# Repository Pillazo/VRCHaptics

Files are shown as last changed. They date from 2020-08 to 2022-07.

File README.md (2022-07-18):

# VRCHaptics
 VRC Haptics
A haptics set of software and hardware to give haptic feedback to VRChat on more than just your controllers. Old version used a melon-loader side-loaded dll file to pull bone positions out and set haptics. New version now uses the approved OSC system, by setting up the avatar in unity with 'VRC Contact Recievers'. A VB.NET program then grabs the OSC commands and then determines to turn on or off vibrating nodes you've mounted to yourself wherever!

A working example video here: https://youtu.be/_tgKSILLgIA

Node Assembly Video: https://youtu.be/x2D46sjlmms

Controller Assembly Video: https://youtu.be/UboYsb8L9xo

Controller Overview and use: https://youtu.be/rSFWYQzmyZ4

VB.Net program and use: https://youtu.be/C1V2dHkt9lk

Adding the Udon to your world: https://youtu.be/wW_y7pmaBFk

Find my project's discord at https://discord.gg/QjyNznq

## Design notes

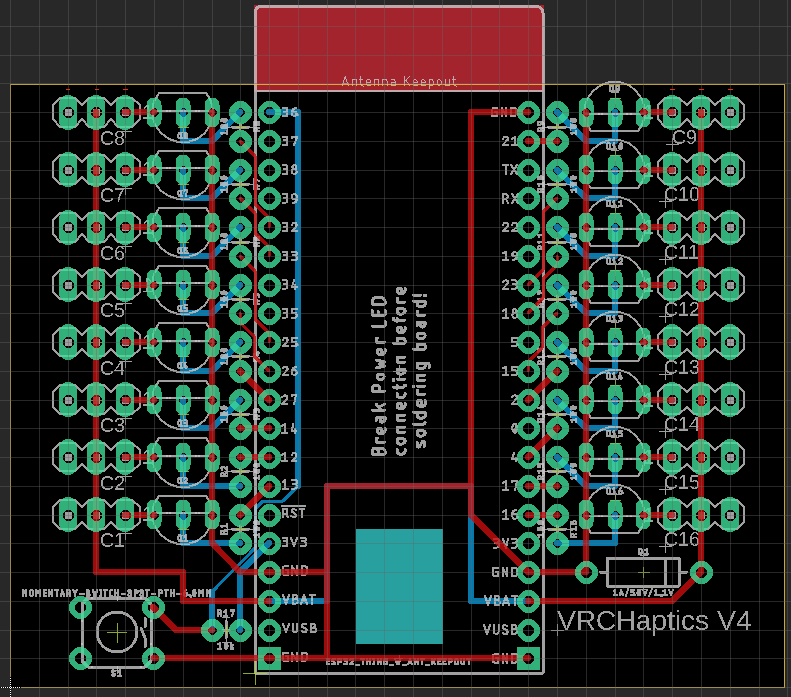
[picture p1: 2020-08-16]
Haptics Hardware/BoardLayout.PNG

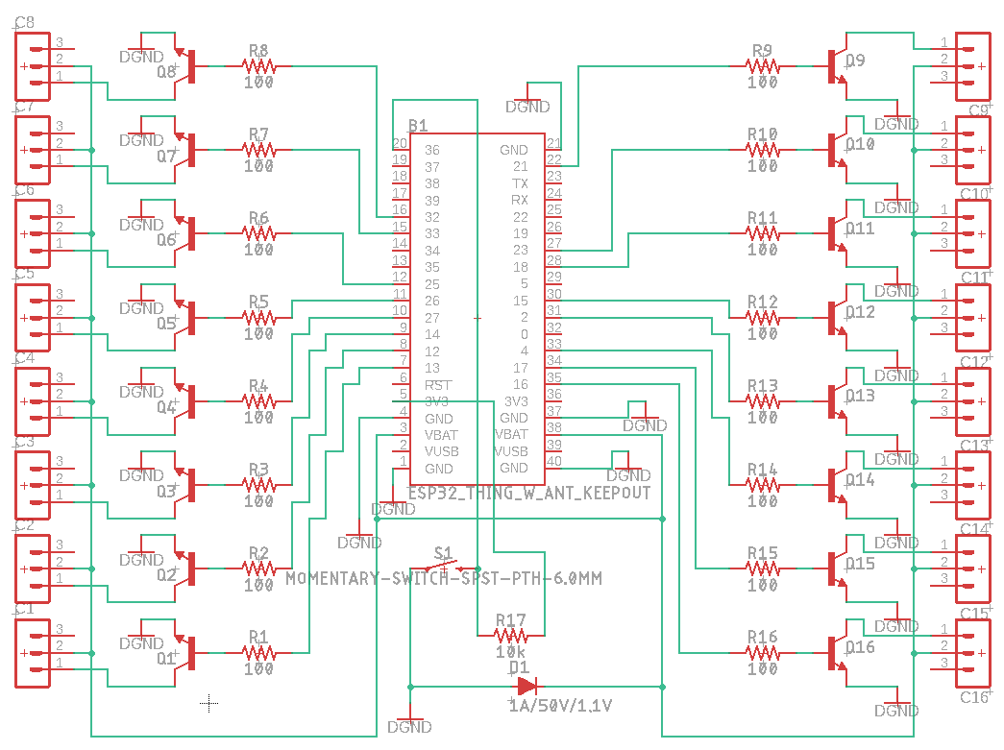
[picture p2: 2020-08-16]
Haptics Hardware/Schematic.PNG

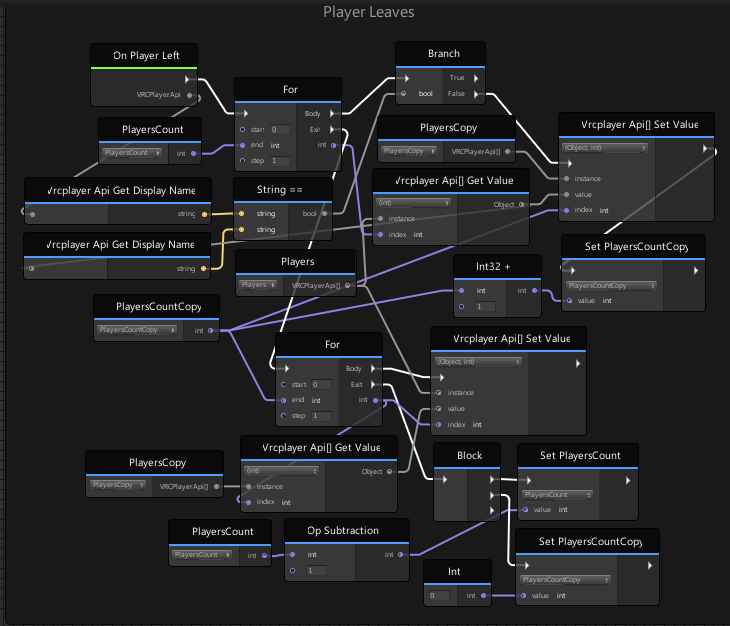
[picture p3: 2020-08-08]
VRChat Udon/Player Leaves.PNG

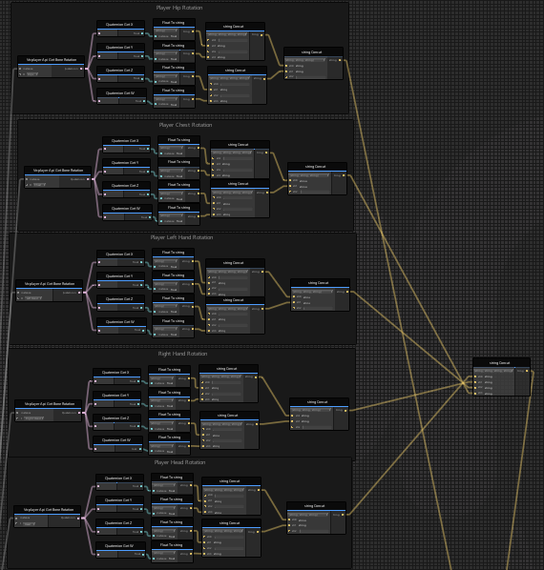
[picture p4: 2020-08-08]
VRChat Udon/Player Rotations.PNG

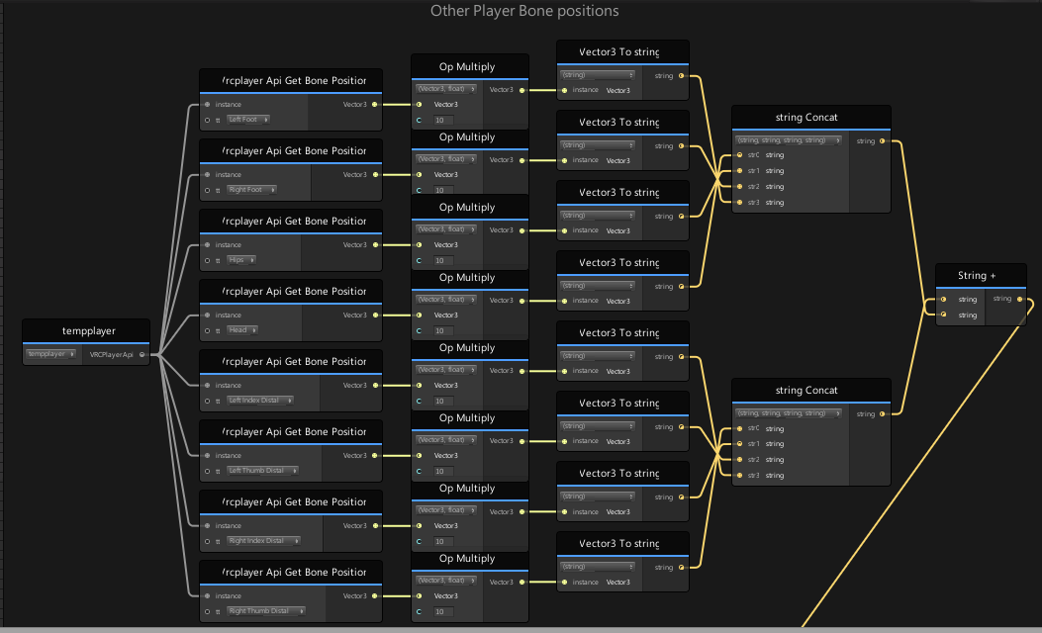
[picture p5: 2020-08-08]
VRChat Udon/Other player bones.PNG

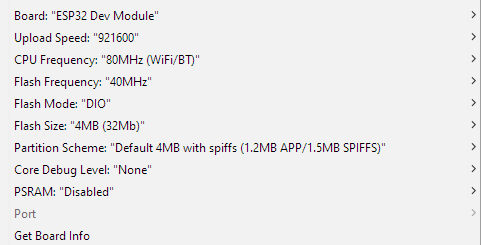
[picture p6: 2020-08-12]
VRCHaptics Controller Software/Settings.PNG

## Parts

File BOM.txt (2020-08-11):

25 Piece Cables
https://www.amazon.com/25Pcs-Remote-Control-Extension-Female/dp/B07L28M5W4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

Long Cables
https://www.amazon.com/gp/product/B01HLUZQ5A/ref=ppx_yo_dt_b_asin_title_o01_s00?ie=UTF8&psc=1

Jumper Wire (to be divided to 2)
https://www.sparkfun.com/products/13164
https://www.amazon.com/gp/product/B016RJ8S42/ref=ppx_yo_dt_b_asin_title_o00_s00?ie=UTF8&psc=1

Battery
https://www.sparkfun.com/products/13855 2Ah
https://www.adafruit.com/product/2011 2Ah

Controller
https://www.sparkfun.com/products/13907
https://www.amazon.com/gp/product/B01MG9BNEN/ref=ppx_yo_dt_b_asin_title_o04_s01?ie=UTF8&psc=1

Vibe Motor
https://www.digikey.com/product-detail/en/1201/1528-1177-ND/5353637/?itemSeq=325918176
https://www.amazon.com/gp/product/B07Q1ZV4MJ/ref=ppx_yo_dt_b_asin_title_o03_s01?ie=UTF8&psc=1

Headers
https://www.amazon.com/gp/product/B06ZZN8L9S/ref=ppx_yo_dt_b_asin_title_o04_s01?ie=UTF8&psc=1
https://www.sparkfun.com/products/116
https://www.adafruit.com/product/392

Nylon Strap 1 inch
https://www.amazon.com/gp/product/B01KTVB0LC/ref=ppx_yo_dt_b_asin_title_o02_s00?ie=UTF8&psc=1

Velcro strap
https://www.homedepot.com/p/VELCRO-Brand-12-ft-x-3-4-in-One-Wrap-Strap-90340/202261925
https://www.amazon.com/VELCRO-Brand-ONE-WRAP-Tape-Yard/dp/B00RPOY384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

Bolt M3x20mm
https://www.amazon.com/gp/product/B07CJLVC17/ref=ppx_yo_dt_b_asin_title_o00_s00?ie=UTF8&psc=1

Bolt M3x10mm
https://www.amazon.com/gp/product/B07CK3RSN3/ref=ppx_yo_dt_b_asin_title_o00_s00?ie=UTF8&psc=1

Push button
https://www.sparkfun.com/products/97
https://www.adafruit.com/product/367
https://www.amazon.com/QTEATAK-Momentary-Tactile-Button-Switch/dp/B07VSNN9S2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

Diode
https://www.sparkfun.com/products/8589
https://www.adafruit.com/product/755
https://www.amazon.com/MCIGICM-Rectifier-Electronic-Silicon-Doorbell/dp/B071YWNBVM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

transistor
https://www.sparkfun.com/products/13689
https://www.adafruit.com/product/756
https://www.amazon.com/McIgIcM-2N2222-Transistor-2N2222A-Through/dp/B06XPWS52G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

resistor 100 ohm
https://www.adafruit.com/product/4293
https://www.sparkfun.com/products/14493
https://www.amazon.com/Projects-100EP514100R-100-Resistors-Pack/dp/B00AVSDYFO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

resistor 10K ohm
https://www.adafruit.com/product/2784
https://www.sparkfun.com/products/14491
https://www.amazon.com/Projects-100EP51410K0-10k-Resistors-Pack/dp/B0185FGYQA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

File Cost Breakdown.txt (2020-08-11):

Controller:
3D Prints (JT3DP Prices)
	-Main Body Top - $11
	-Main Body Board Holder - $8.50
	-Main Body Battery Adafruit - $12 / Main body Battery Sparkfun - $10
	-Main Body button - $0.50
	-Main Body Clip - $8.50 / Main Body Strap Mount - $7
Components
	-Sparkfun ESP32 Thing - $19.28
	-Battery - $13 Sparkfun, $12.50 Adafruit
	-Circuit Board - $25, $2.50ea
	-2x 20pos Headers - $11, $0.055ea
	-16x 3pos headers - $11, $0.00825ea
	-16x 100 ohm resistors - $0.75, 0.03ea
	-10K ohm resisitor - $0.75, 0.03ea
	-Push button - $2.50, 0.125ea
	-Diode - $0.15ea
	-16x Transistors - $1.95, $0.195ea
	-4x M3x20mm bolt - $9, $0.09ea
	-3x / 2x M3x10mm bolt - $7.65, $0.0765ea
	
Total:
3D print for adafruit battery and strap mount - $39
3D print for adafruit battery and clip mount - $40.5
3D print for sparkfun battery and strap mount - $37
3D print for sparkfun battery and clip mount - $38.5
Components for adafruit battery - $39
Components for sparkfun battery - $39.50

Total adafruit battery cost = $78
Total sparkfun battery cost = $76.5

Node
16x 3D Print - 1in - $4
16x 3D Print - 0.75in - $3.50
16x Vibration Motor - $15, $0.75ea
16x Half Servo Cable - $8, $0.40ea
Velcro 3/4in strap - $0.34/ft - 12ft = $4.08
2x / 2x M3x10mm bolt - $7.65, $0.0765ea

Cables
	-Assorted length extensions - $12, $0.60ea
	-1 meter length extensions - $21.47, $0.72ea
	
Velcro Straps

Total: 16x - 1in $84.96, 5.31ea
		   - .75in $76.8, 4.80ea

Total controller + 16 Nodes = $153
Total controller + 16 nodes + 16 1-meter cables  + 12ft velcro = $168.9
+ shipping for battery = 182.73

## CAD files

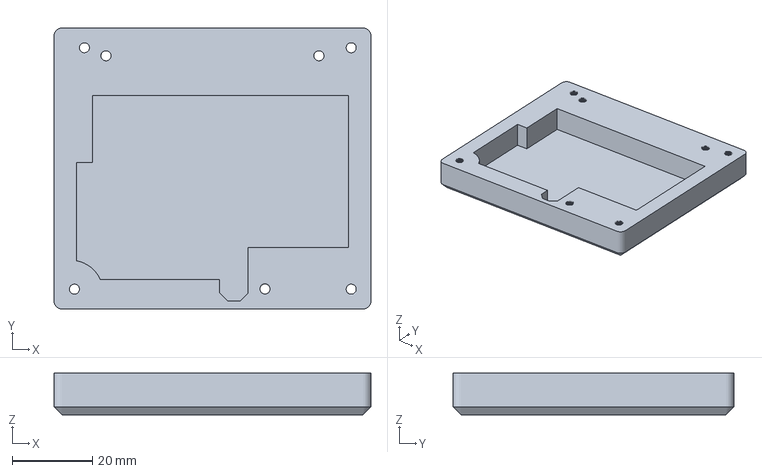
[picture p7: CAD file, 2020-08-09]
VRCHaptics 3D files/Main Body Adafruit Battery.3mf
79.2 x 70.2 x 10.4 mm

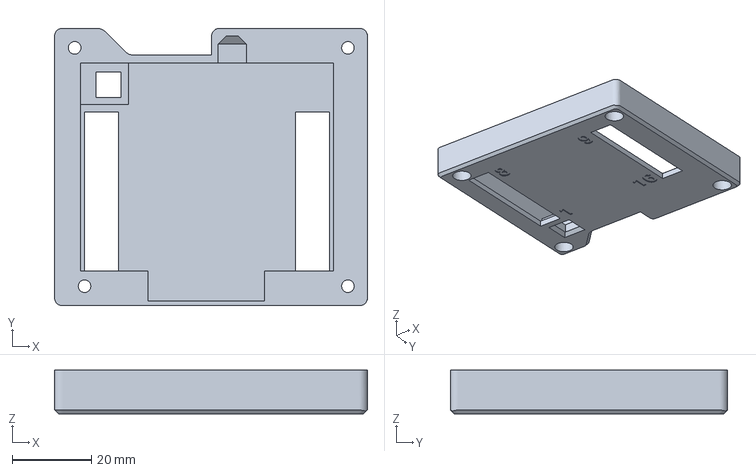
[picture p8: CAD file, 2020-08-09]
VRCHaptics 3D files/Main Body.3mf
79.2 x 70.2 x 11.1 mm

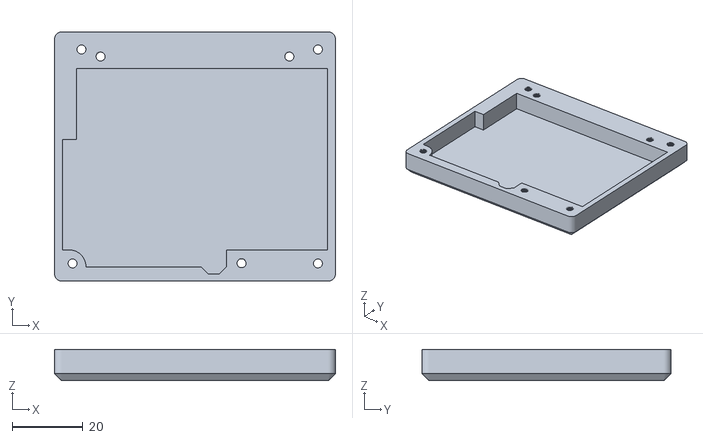
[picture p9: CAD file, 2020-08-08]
VRCHaptics 3D files/Main Body SparkFun Battery.stl
79.2 x 70.2 x 8.80

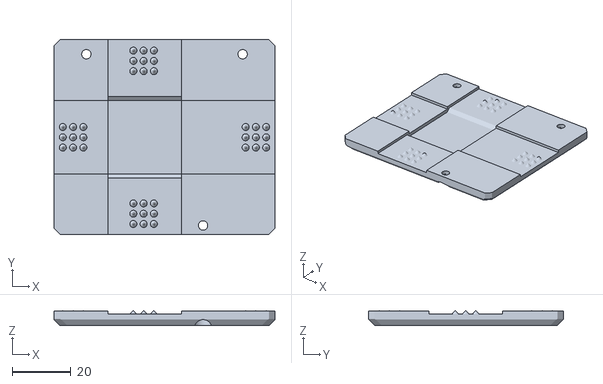
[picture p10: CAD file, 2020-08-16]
VRCHaptics 3D files/Strip Mount.stl
75.2 x 66.2 x 5.10

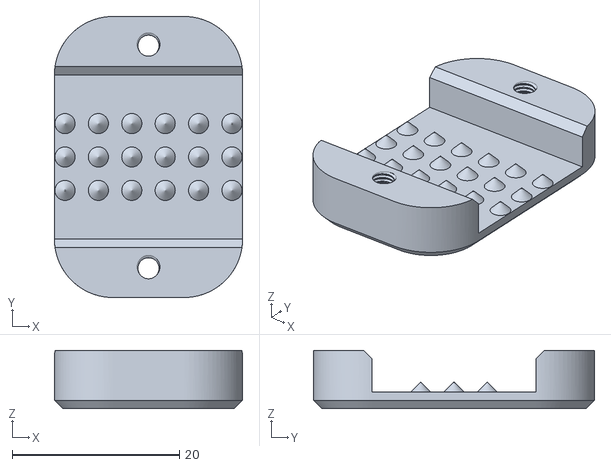
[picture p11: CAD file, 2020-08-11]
VRCHaptics 3D files/NodeBottom2Way-.75in.stl
22.5 x 33.7 x 7.00

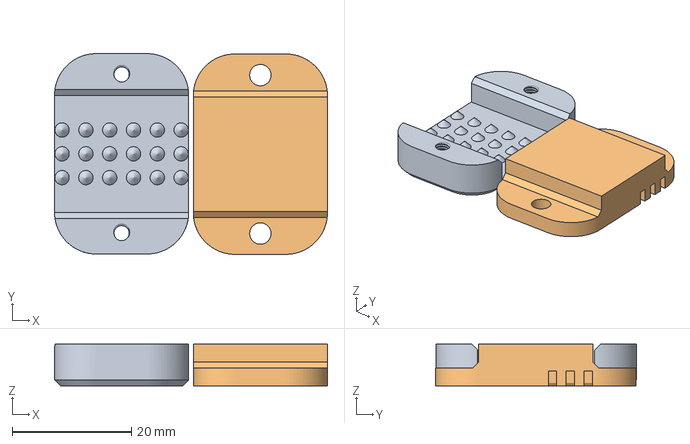
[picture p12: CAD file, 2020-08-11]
VRCHaptics 3D files/Node2Way-.75in.3mf
45.8 x 33.7 x 7.00 mm
NodeBottom2Way-.75in.stl
NodeTop2Way-.75in.stl

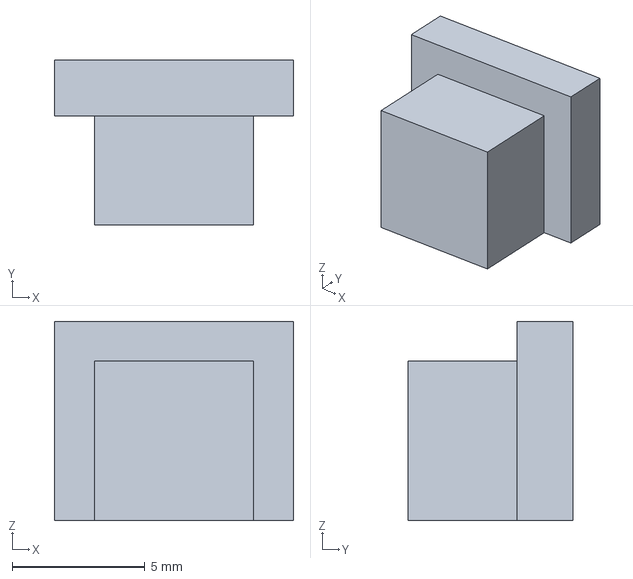
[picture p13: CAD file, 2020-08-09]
VRCHaptics 3D files/Button.3mf
9.00 x 6.20 x 7.50 mm

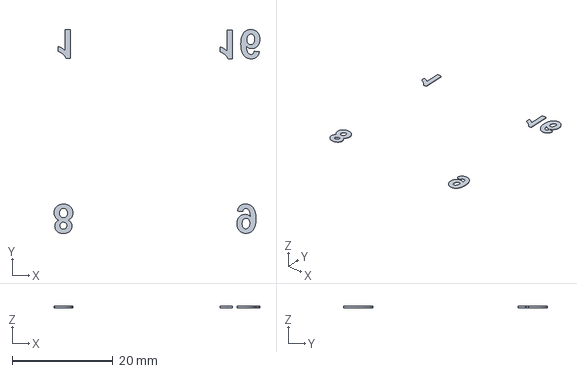
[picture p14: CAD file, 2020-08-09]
VRCHaptics 3D files/Text.3mf
40.9 x 40.5 x 0.3 mm

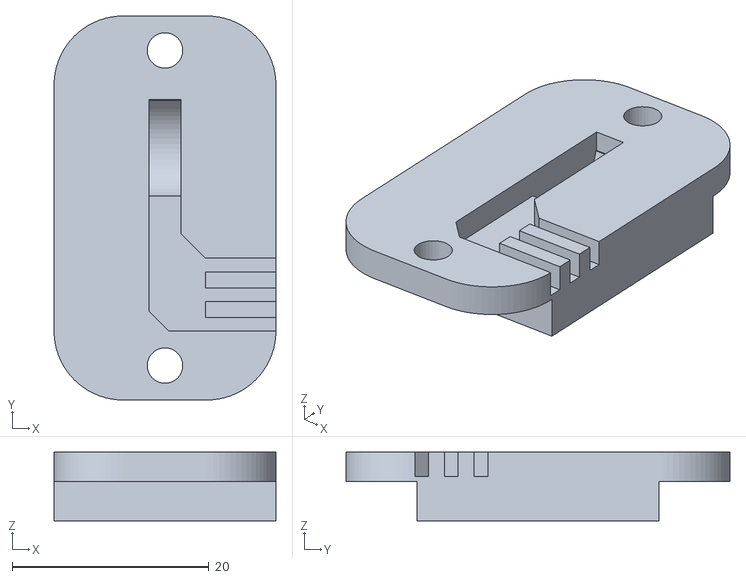
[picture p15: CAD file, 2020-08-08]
VRCHaptics 3D files/NodeTop2Way.stl
22.5 x 39.0 x 7.00

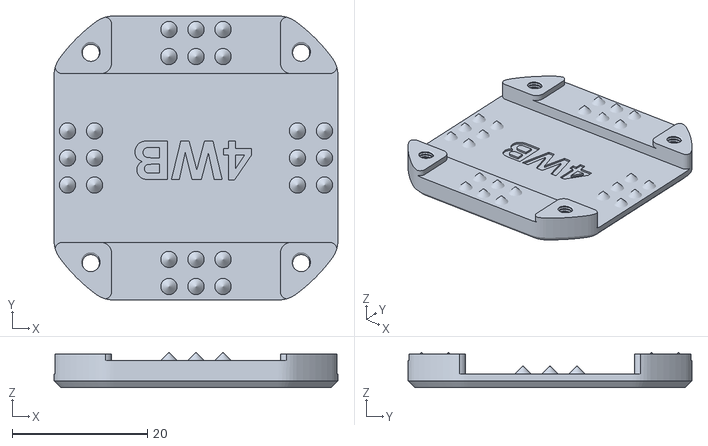
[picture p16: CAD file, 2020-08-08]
VRCHaptics 3D files/NodeBottom4Way.stl
42.0 x 42.0 x 5.21

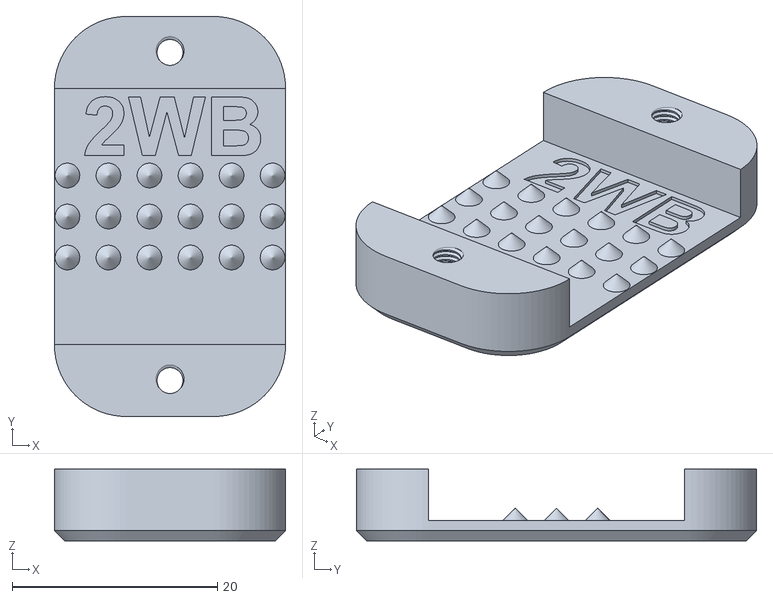
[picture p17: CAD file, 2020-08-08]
VRCHaptics 3D files/NodeBottom2Way.stl
22.5 x 39.0 x 7.00

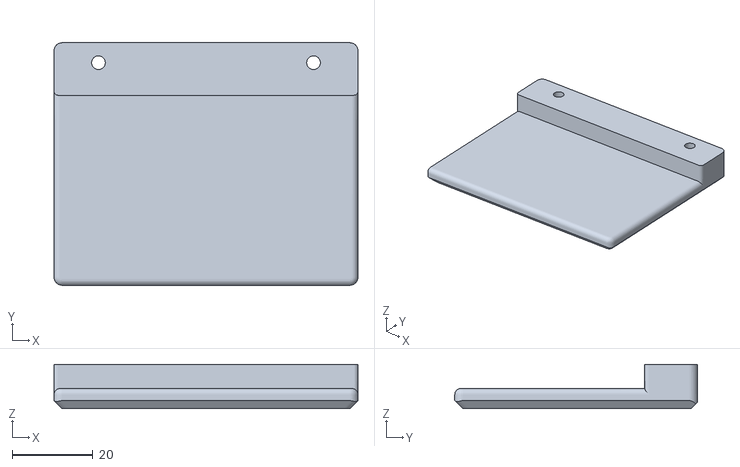
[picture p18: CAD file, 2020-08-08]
VRCHaptics 3D files/Clip.stl
75.2 x 60.0 x 11.0

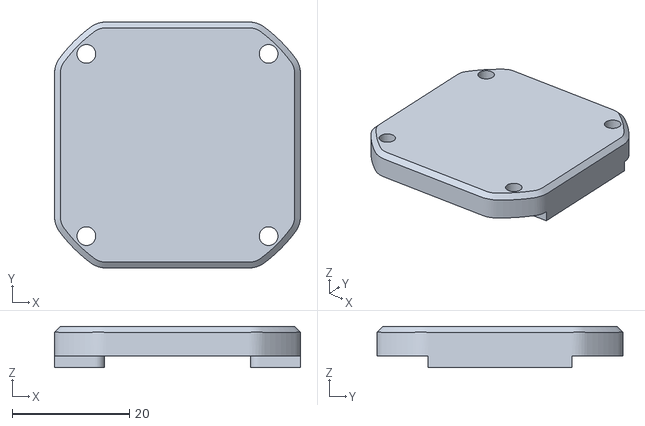
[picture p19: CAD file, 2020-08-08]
VRCHaptics 3D files/NodeTop4Way.stl
42.0 x 42.0 x 7.00

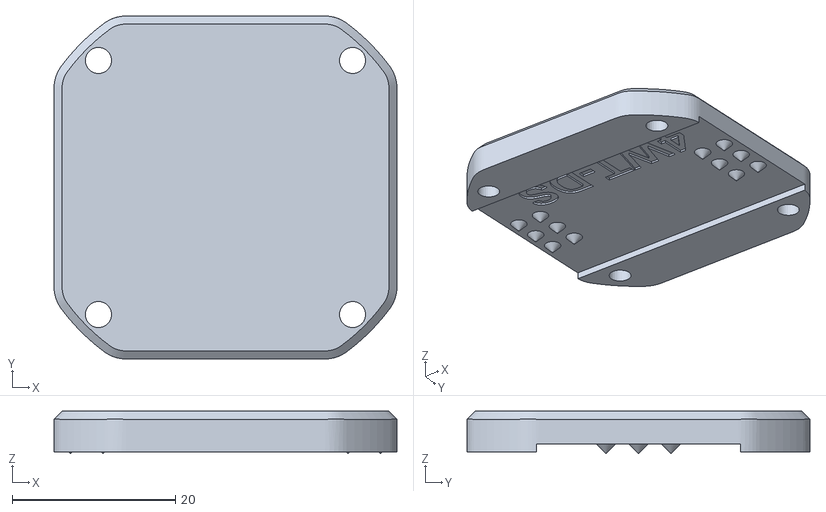
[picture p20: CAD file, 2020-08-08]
VRCHaptics 3D files/NodeTop4Way-DoubleStrap.stl
42.0 x 42.0 x 5.21

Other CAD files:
VRCHaptics 3D files/NodeTop2Way-.75in.stl
VRCHaptics 3D files/Ring.stl
VRCHaptics 3D files/Main Body (1).3mf
VRCHaptics 3D files/Button.stl
VRCHaptics 3D files/Main Body (1).stl
VRCHaptics 3D files/Main Body Adafruit Battery.stl
VRCHaptics 3D files/Main Body.stl
VRCHaptics 3D files/Text.stl

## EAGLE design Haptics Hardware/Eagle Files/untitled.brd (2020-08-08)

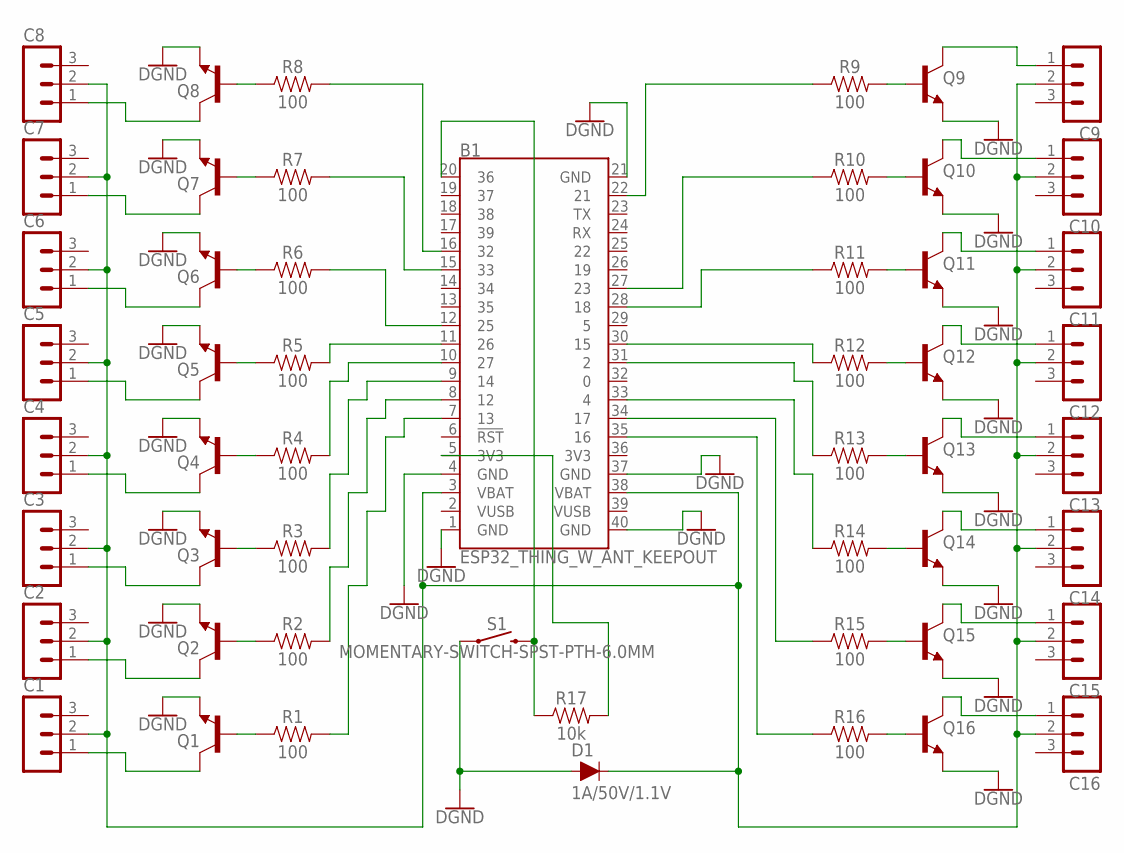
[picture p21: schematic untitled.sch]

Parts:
B1: ESP32_THING_W_ANT_KEEPOUT; ESP32_THING
C1, C2, C3, C4, C5, C6, C7, C8, C9, C10, C11, C12, C13, C14, C15, C16: MA03-1
D1: 1A/50V/1.1V; DIODE-1N4001
Q1, Q2, Q3, Q4, Q5, Q6, Q7, Q8, Q9, Q10, Q11, Q12, Q13, Q14, Q15, Q16: 600mA/40V; TO92-EBC
R1, R2, R3, R4, R5, R6, R7, R8, R9, R10, R11, R12, R13, R14, R15, R16: 100; AXIAL-0.1
R17: 10k; AXIAL-0.1
S1: MOMENTARY-SWITCH-SPST-PTH-6.0MM; TACTILE_SWITCH_PTH_6.0MM

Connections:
GND: B1.1 (GND), B1.4 (GND), B1.21 (GND), B1.37 (GND), B1.40 (GND), D1.A, Q1.E, Q2.E, Q3.E, Q4.E, Q5.E, Q6.E, Q7.E, Q8.E, Q9.E, Q10.E, Q11.E, Q12.E, Q13.E, Q14.E, Q15.E, Q16.E, S1.1
unnamed: B1.11 (26), R5.P$2 (2)
unnamed: B1.22 (21), R9.P$1 (1)
unnamed: Q9.B, R9.P$2 (2)
unnamed: B1.27 (23), R10.P$1 (1)
unnamed: B1.10 (27), R4.P$2 (2)
unnamed: B1.28 (18), R11.P$1 (1)
unnamed: B1.35 (16), R16.P$1 (1)
unnamed: B1.34 (17), R15.P$1 (1)
unnamed: B1.33 (4), R14.P$1 (1)
unnamed: Q16.B, R16.P$2 (2)
unnamed: Q15.B, R15.P$2 (2)
unnamed: Q14.B, R14.P$2 (2)
unnamed: Q13.B, R13.P$2 (2)
unnamed: Q12.B, R12.P$2 (2)
unnamed: Q11.B, R11.P$2 (2)
unnamed: Q10.B, R10.P$2 (2)
unnamed: B1.31 (2), R13.P$1 (1)
unnamed: B1.30 (15), R12.P$1 (1)
unnamed: Q2.B, R2.P$1 (1)
unnamed: Q1.B, R1.P$1 (1)
unnamed: Q3.B, R3.P$1 (1)
unnamed: Q4.B, R4.P$1 (1)
unnamed: Q5.B, R5.P$1 (1)
unnamed: Q6.B, R6.P$1 (1)
unnamed: Q7.B, R7.P$1 (1)
unnamed: Q8.B, R8.P$1 (1)
unnamed: C8.1, Q8.C
unnamed: C7.1, Q7.C
unnamed: C6.1, Q6.C
unnamed: C5.1, Q5.C
unnamed: C4.1, Q4.C
unnamed: C3.1, Q3.C
unnamed: C2.1, Q2.C
unnamed: C1.1, Q1.C
unnamed: C16.1, Q16.C
unnamed: C15.1, Q15.C
unnamed: C14.1, Q14.C
unnamed: C13.1, Q13.C
unnamed: C12.1, Q12.C
unnamed: C11.1, Q11.C
unnamed: C10.1, Q10.C
unnamed: C9.1, Q9.C
unnamed: B1.3 (VBAT), B1.38 (VBAT), C1.2, C2.2, C3.2, C4.2, C5.2, C6.2, C7.2, C8.2, C9.2, C10.2, C11.2, C12.2, C13.2, C14.2, C15.2, C16.2, D1.C
unnamed: B1.20 (36), R17.P$1 (1), S1.3 (2)
unnamed: B1.9 (14), R3.P$2 (2)
unnamed: B1.16 (32), R8.P$2 (2)
unnamed: B1.15 (33), R7.P$2 (2)
unnamed: B1.12 (25), R6.P$2 (2)
unnamed: B1.8 (12), R2.P$2 (2)
unnamed: B1.7 (13), R1.P$2 (2)
unnamed: B1.5 (3V3), R17.P$2 (2)

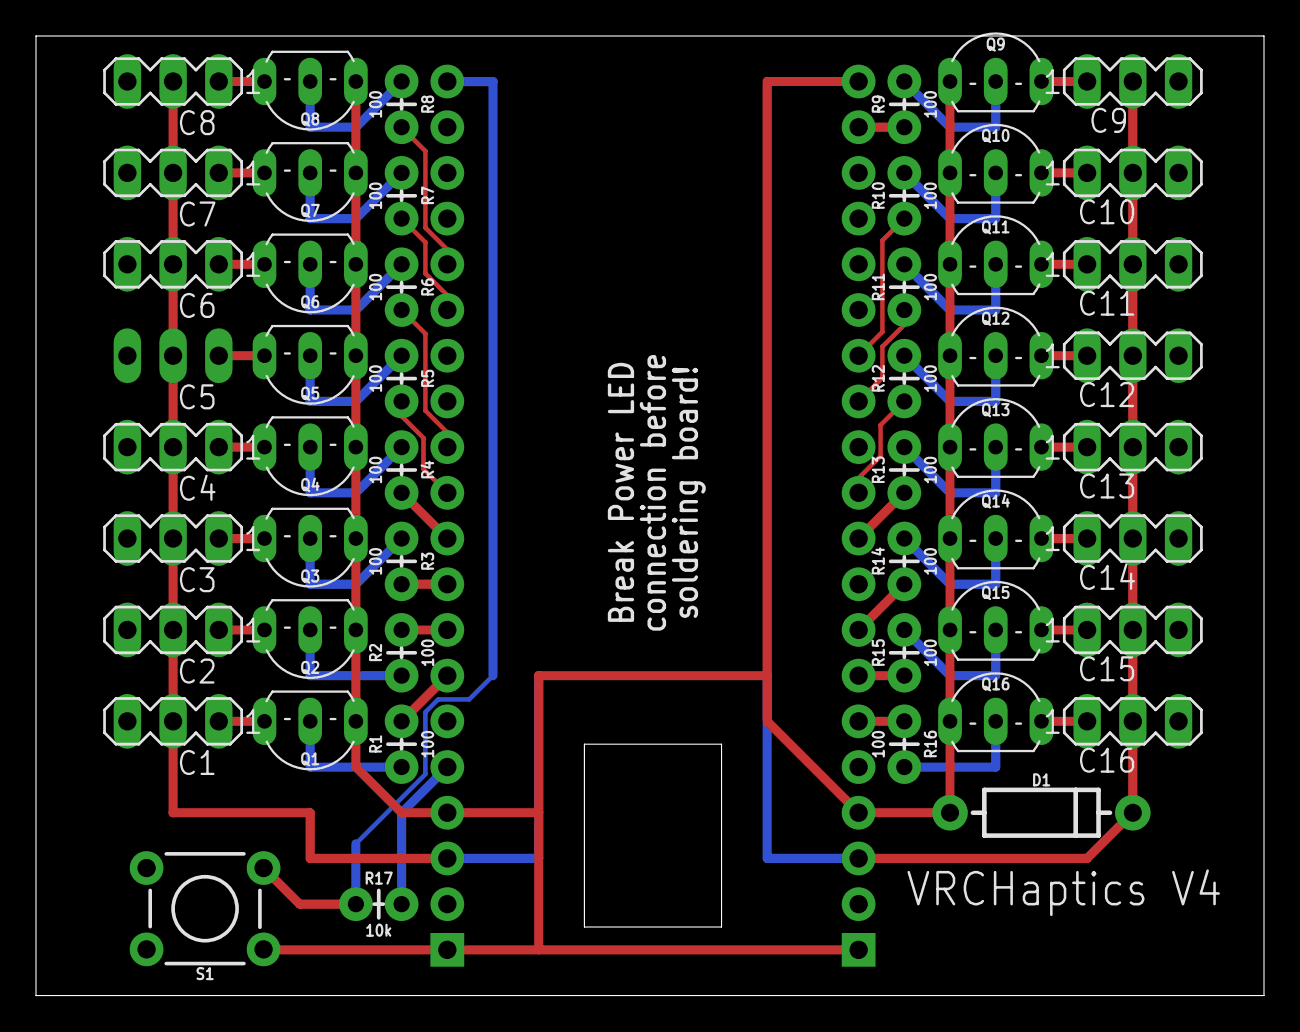
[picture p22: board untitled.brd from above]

Board: 2 copper layers, 68.2 x 53.3 mm, 52 parts (1 on the bottom side), 52 nets.

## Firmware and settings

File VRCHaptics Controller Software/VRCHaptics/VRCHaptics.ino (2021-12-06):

//VRCHaptics controller code, started by Pillazo

#include <WiFi.h> //This area calls out subprograms for reference
#include "AsyncUDP.h"
#include <EEPROM.h>
#include <esp_bt.h>
#include <esp_bt_main.h>
#include <driver/adc.h>

const int BUTTON_PIN = 36; //Pin 36 of the ESP32 is where the pushbutton is assigned
const int LED_PIN = 5; //The LED pin of the ESP32 is already wired to the board

const int freq = 5000;  //truly a random number, sounded good
const int resolution = 8; //eight bits, easy peasy

const int Output01 = 13;  //Assigning the ESP32 pins to my order of outputs
const int Output02 = 12;
const int Output03 = 14;
const int Output04 = 27;
const int Output05 = 26;
const int Output06 = 25;
const int Output07 = 33;
const int Output08 = 32;
const int Output09 = 21;
const int Output10 = 23;
const int Output11 = 18;
const int Output12 = 15;
const int Output13 = 2;
const int Output14 = 4;
const int Output15 = 17;
const int Output16 = 16;

int LedFlashTimer = 0;  //This was kind of a debug thing

int Output01Time = 0; //Each pin is given a signal to start, for a certain length of time, once its reached zero, it turns off
int Output02Time = 0;
int Output03Time = 0;
int Output04Time = 0;
int Output05Time = 0;
int Output06Time = 0;
int Output07Time = 0;
int Output08Time = 0;
int Output09Time = 0;
int Output10Time = 0;
int Output11Time = 0;
int Output12Time = 0;
int Output13Time = 0;
int Output14Time = 0;
int Output15Time = 0;
int Output16Time = 0;

int Output01Power = 0; //Intensity of each output, as given by the VB.net program
int Output02Power = 0;
int Output03Power = 0;
int Output04Power = 0;
int Output05Power = 0;
int Output06Power = 0;
int Output07Power = 0;
int Output08Power = 0;
int Output09Power = 0;
int Output10Power = 0;
int Output11Power = 0;
int Output12Power = 0;
int Output13Power = 0;
int Output14Power = 0;
int Output15Power = 0;
int Output16Power = 0;

char networkName[50]; //The wifi SSID (wifi name)
char networkPswd[50]; //Wifi password
char deviceName[50];  //The name given to the device so it can recognize its packets
int deviceNameLen = 0; //Another quick tool to help it recognize its own packets
AsyncUDP udp; //Call out the UDP for use
const int port = 42069; // Random port I pulled out of the air
IPAddress broadcast=IPAddress(239,80,8,5); //Random IP in the multicast range I pulled out the air too
int DeviceNameBroadcastCountup = 0; //This is a counter/timer for every now and then spitting the device name out to the UDP, so the VB.net program can see the controller and mark it green
bool thisDevice = false; //The 'is this packet for this device?' bit
int dataStart = 0;  //Start point in the packet for the actual outputs after the name
int dataIndex = 0;  //Indexing through the data
int FactoryResetTimer = 0; //Used for the button press, if pressed, add time to this timer
int ledState = 0; //Used for flipping the LED during connection

void setup(){   //Actual start of code, this is the setup area
  EEPROM.begin(512);  //Needed to store data on the ESP32, defines 512 bytes
  // Initilize hardware:
  esp_sleep_enable_ext0_wakeup(GPIO_NUM_36,0); //Input pin 36, going low, wakes up the device from sleep
  touch_pad_intr_disable(); //Disable all the touch capability of the ESP32
  Serial.begin(115200); //Setup communication to the computer via USB
  Serial.setTimeout(50);  //Timeout cause timeout, ya know?
  pinMode(BUTTON_PIN, INPUT); //The push button is an input to the ESP32 lol
  pinMode(LED_PIN, OUTPUT); //The LED and all the outputs are outs of the ESP32 lol
  pinMode(Output01, OUTPUT);
  pinMode(Output02, OUTPUT);
  pinMode(Output03, OUTPUT);
  pinMode(Output04, OUTPUT);
  pinMode(Output05, OUTPUT);
  pinMode(Output06, OUTPUT);
  pinMode(Output07, OUTPUT);
  pinMode(Output08, OUTPUT);
  pinMode(Output09, OUTPUT);
  pinMode(Output10, OUTPUT);
  pinMode(Output11, OUTPUT);
  pinMode(Output12, OUTPUT);
  pinMode(Output13, OUTPUT);
  pinMode(Output14, OUTPUT);
  pinMode(Output15, OUTPUT);
  pinMode(Output16, OUTPUT);
  
  ledcSetup(0, freq, resolution); //This area sets up the PWM of the outputs, allowing them to have intensity
  ledcSetup(1, freq, resolution);
  ledcSetup(2, freq, resolution);
  ledcSetup(3, freq, resolution);
  ledcSetup(4, freq, resolution);
  ledcSetup(5, freq, resolution);
  ledcSetup(6, freq, resolution);
  ledcSetup(7, freq, resolution);
  ledcSetup(8, freq, resolution);
  ledcSetup(9, freq, resolution);
  ledcSetup(10, freq, resolution);
  ledcSetup(11, freq, resolution);
  ledcSetup(12, freq, resolution);
  ledcSetup(13, freq, resolution);
  ledcSetup(14, freq, resolution);
  ledcSetup(15, freq, resolution);

  ledcAttachPin(Output01, 0); //Previous section just parameterized the intensity stuff, this actually assigns them to the outputs
  ledcAttachPin(Output02, 1);
  ledcAttachPin(Output03, 2);
  ledcAttachPin(Output04, 3);
  ledcAttachPin(Output05, 4);
  ledcAttachPin(Output06, 5);
  ledcAttachPin(Output07, 6);
  ledcAttachPin(Output08, 7);
  ledcAttachPin(Output09, 8);
  ledcAttachPin(Output10, 9);
  ledcAttachPin(Output11, 10);
  ledcAttachPin(Output12, 11);
  ledcAttachPin(Output13, 12);
  ledcAttachPin(Output14, 13);
  ledcAttachPin(Output15, 14);
  ledcAttachPin(Output16, 15);
  
  detachInterrupt(0); //Any interrupt can go away
  detachInterrupt(1);
  detachInterrupt(2);
  detachInterrupt(3);
  detachInterrupt(4);
  detachInterrupt(5);
  detachInterrupt(12);
  detachInterrupt(13);
  detachInterrupt(14);
  detachInterrupt(15);
  detachInterrupt(16);
  detachInterrupt(17);
  detachInterrupt(18);
  detachInterrupt(19);
  detachInterrupt(21);
  detachInterrupt(22);
  detachInterrupt(23);
  detachInterrupt(25);
  detachInterrupt(26);
  detachInterrupt(27);
  detachInterrupt(32);
  detachInterrupt(33);
  detachInterrupt(34);
  detachInterrupt(35);
  detachInterrupt(36);
  detachInterrupt(37);
  detachInterrupt(38);
  detachInterrupt(39);

  esp_bt_controller_disable();  //Disable all bluetooth
  esp_bluedroid_deinit(); 
  esp_bluedroid_disable();
  adc_power_off();  //Disable the analog to digital conversion stuff too
  
  WiFiReset();  //This is a subroutine at the end of the program, resets the wifi
  
  udp.listenMulticast(broadcast, port);
  
  memset(networkName, 0, sizeof(networkName));  //Clear out the network SSID, password and device name to defaults
  memset(networkPswd, 0, sizeof(networkPswd)); 
  memset(deviceName, 0, sizeof(deviceName));
  networkName[0] = '^';
  networkPswd[0] = '^';
  deviceNameLen = 0;

  for (int i = 0 ; i < 50 ; i++) {  //Now that its cleared, read in the stuff from memory
    networkName[i] = EEPROM.read(i);
  }    
  for (int i = 0 ; i < 50 ; i++) {
    networkPswd[i] = EEPROM.read(i+50);
  }    
  for (int i = 0 ; i < 50 ; i++) {
    deviceName[i] = EEPROM.read(i+100);
  } 
  deviceNameLen = EEPROM.read(150);
  Serial.print("Wifi:");  //Spit it out of the USB communication
  Serial.print(networkName);
  Serial.println(".");
  Serial.print("Pass:");
  Serial.print("***");
  Serial.println(".");   
  Serial.print("Device Name:");
  Serial.print(deviceName);
  Serial.println(".");

  digitalWrite(LED_PIN, HIGH);  //Turn on the LED
  ledcWrite(0, 0);  //Tell all the intensity stuff to be off
  ledcWrite(1, 0);
  ledcWrite(2, 0);
  ledcWrite(3, 0);
  ledcWrite(4, 0);
  ledcWrite(5, 0);
  ledcWrite(6, 0);
  ledcWrite(7, 0);
  ledcWrite(8, 0);
  ledcWrite(9, 0);
  ledcWrite(10, 0);
  ledcWrite(11, 0);
  ledcWrite(12, 0);
  ledcWrite(13, 0);
  ledcWrite(14, 0);
  ledcWrite(15, 0);
  
}

void loop(){  //Main loop of the program! Starts after the setup code above
  
  delay(10);  //Default delay, no reason to run like crazy
  
  LedFlashTimer = LedFlashTimer + 1;  //Debug stuff, can probably ignore it, may remove later
  if (LedFlashTimer >= 400){
    LedFlashTimer = 0;
    //digitalWrite(LED_PIN, LOW);  
  }
    
  if (digitalRead(BUTTON_PIN) == LOW) { //Default the button is held high! so this means its being pressed, add to the timer!
    FactoryResetTimer = FactoryResetTimer + 1;
  }
   if (digitalRead(BUTTON_PIN) == HIGH) { //If the button is let go, see where timer ended up     
      if (FactoryResetTimer > 500){ //If its more than 5 seconds (500count x 10ms delay = 5s), then run factory reset
        digitalWrite(LED_PIN, HIGH);  //Blink the LED twice just cause
        delay(100);
        digitalWrite(LED_PIN, LOW);
        delay(500);
        digitalWrite(LED_PIN, HIGH);
        delay(100);
        digitalWrite(LED_PIN, LOW);
        delay(500);
        digitalWrite(LED_PIN, HIGH);
        delay(100);
        digitalWrite(LED_PIN, LOW);
        delay(500);
        FactoryResetTimer = 0;  //Clear the timer
        memset(networkName, 0, sizeof(networkName)); //Reset the network name, password and device name  
        memset(networkPswd, 0, sizeof(networkPswd)); 
        memset(deviceName, 0, sizeof(deviceName));
        networkName[0] = '^'; //Give them default values
        networkPswd[0] = '^';
        deviceNameLen = 0;
        for (int i = 0 ; i < 50 ; i++) {  //Also clear out the device memory too so it doesn't start up with old values
          EEPROM.write(i,networkName[i]);
        }    
        for (int i = 0 ; i < 50 ; i++) {
          EEPROM.write(i+50,networkPswd[i]);
        }    
        for (int i = 0 ; i < 50 ; i++) {
          EEPROM.write(i+100,deviceName[i]);
        } 
        EEPROM.write(150,deviceNameLen);
        EEPROM.commit();  //Apply that stuff to memory
        delay(500); //Wait half second
        Serial.println("Factory Reset..."); //Spit data to USB
        WiFiReset();    //Reset Wifi so its no longer connected to old stuff if it was
        digitalWrite(LED_PIN, HIGH); //Set LED high
      }
      
      if (FactoryResetTimer > 10){ //If it was simply just longer than 0.1 second, then put the device to sleep
        Serial.println("Going to sleep"); //Send sleep message to USB
        digitalWrite(LED_PIN, LOW); //Turn off LED
        ledcWrite(0, 0);  //Turn off all outputs
        ledcWrite(1, 0);
        ledcWrite(2, 0);
        ledcWrite(3, 0);
        ledcWrite(4, 0);
        ledcWrite(5, 0);
        ledcWrite(6, 0);
        ledcWrite(7, 0);
        ledcWrite(8, 0);
        ledcWrite(9, 0);
        ledcWrite(10, 0);
        ledcWrite(11, 0);
        ledcWrite(12, 0);
        ledcWrite(13, 0);
        ledcWrite(14, 0);
        ledcWrite(15, 0); 
        //udp.close();       
        delay(5000); //Wait 5 whole seconds
        esp_deep_sleep_start(); //Put device to sleep, when it wakes up by the push button it starts at the top of setup
      }
        FactoryResetTimer = 0; //If it wasn't pressed long enough for any of these, just clear it out to start it over for next time
    }


  
  if (WiFi.status() != WL_CONNECTED){ //If device is not yet connected to wifi...
     if (LedFlashTimer == 95){ //Debug stuff, probably remove later
      //digitalWrite(LED_PIN, HIGH);
      Serial.println("Connecting to wifi"); //Give info out USB
    }
    connectToWiFi();  //Call wifi connection sub routine (see below)
  }
  if (WiFi.status() == WL_CONNECTED){ //If it is connected though!
    if (LedFlashTimer == 5){  //Debug stuff, probably remove later
      //digitalWrite(LED_PIN, HIGH);
    }
    //Set outputs
    if (Output01Time > 0){  //If the packet saw that this output was on, it gives it a timer value to run with
      ledcWrite(0, Output01Power);  //Place the intensity into the output and it'll start buzzing
      Output01Time = Output01Time - 1;  //Start decreasing the timer for this output
    }
    else {  //If there's no more time left...
      ledcWrite(0, 0);  //Turn off the output by setting intensity to zero
    }
    if (Output02Time > 0){  //repeat for all other 16 outputs!
      ledcWrite(1, Output02Power);
      Output02Time = Output02Time - 1;
    }
    else {
      ledcWrite(1, 0);
    }
    if (Output03Time > 0){
      ledcWrite(2, Output03Power);
      Output03Time = Output03Time - 1;
    }
    else {
      ledcWrite(2, 0);
    }
    if (Output04Time > 0){
      ledcWrite(3, Output04Power);
      Output04Time = Output04Time - 1;
    }
    else {
      ledcWrite(3, 0);
    }
    if (Output05Time > 0){
      ledcWrite(4, Output05Power);
      Output05Time = Output05Time - 1;
    }
    else {
      ledcWrite(4, 0);
    }
    if (Output06Time > 0){
      ledcWrite(5, Output06Power);
      Output06Time = Output06Time - 1;
    }
    else {
      ledcWrite(5, 0);
    }
    if (Output07Time > 0){
      ledcWrite(6, Output07Power);
      Output07Time = Output07Time - 1;
    }
    else {
      ledcWrite(6, 0);
    }
    if (Output08Time > 0){
      ledcWrite(7, Output08Power);
      Output08Time = Output08Time - 1;
    }
    else {
      ledcWrite(7, 0);
    }
    if (Output09Time > 0){
      ledcWrite(8, Output09Power);
      Output09Time = Output09Time - 1;
    }
    else {
      ledcWrite(8, 0);
    }
    if (Output10Time > 0){
      ledcWrite(9, Output10Power);
      Output10Time = Output10Time - 1;
    }
    else {
      ledcWrite(9, 0);
    }
    if (Output11Time > 0){
      ledcWrite(10, Output11Power);
      Output11Time = Output11Time - 1;
    }
    else {
      ledcWrite(10, 0);
    }
    if (Output12Time > 0){
      ledcWrite(11, Output12Power);
      Output12Time = Output12Time - 1;
    }
    else {
      ledcWrite(11, 0);
    }
    if (Output13Time > 0){
      ledcWrite(12, Output13Power);
      Output13Time = Output13Time - 1;
    }
    else {
      ledcWrite(12, 0);
    }
    if (Output14Time > 0){
      ledcWrite(13, Output14Power);
      Output14Time = Output14Time - 1;
    }
    else {
      ledcWrite(13, 0);
    }
    if (Output15Time > 0){
      ledcWrite(14, Output15Power);
      Output15Time = Output15Time - 1;
    }
    else {
      ledcWrite(14, 0);
    }
    if (Output16Time > 0){
      ledcWrite(15, Output16Power);
      Output16Time = Output16Time - 1;
    }
    else {
      ledcWrite(15, 0);
    }
     
// Recieve Packet
        
      udp.onPacket([](AsyncUDPPacket packet) {  //Get packet from network!
        
          thisDevice = false; //Start with saying this packet isn't for this device
          if (packet.length() >= (deviceNameLen + 23)){  //However if the device's name length in characters and the rest of the standard packet match...
            thisDevice = true; //Set it to a tentative maybe
            for (int i = 0 ; i < deviceNameLen ; i++) { //Go through each character of the name
              if ((char)*(packet.data()+i) != deviceName[i]){ //If it doesn't match
                thisDevice = false; //Then set that this packet isn't for this device
              }
            }
          }
                      
          if (thisDevice == true){  //If we've determined that this packet is for this device then...

            digitalWrite(LED_PIN, ledState);  //Flip the LED output
            ledState = (ledState + 1) % 2; // Flip the LED state
            
            dataStart = 0; //Clear out data start position
            dataIndex = 0; //Clear out data index position
            for (int i = 0 ; i < packet.length() ; i++){  //For every byte of the packet
              if ((char)*(packet.data()+i) == '&'){ //If we find the character '&' then
                dataStart = i + 1;  //Set this as the data starting position
                break;  //Exit this loop that looks for the '&'
              }
                             
            }
            //Serial.println(dataStart);  //Debug
            if (packet.data()+dataStart != 0){ //So if the first byte doesn't equal a hard zero, add a time value to the timer so this output will begin buzzing!
              Output01Time = 10;  //Adding essentially 100ms (0.1 seconds)
              Output01Power = (int)*(packet.data()+dataStart);  //This converts the byte to an intensity (0-255 where 0 is off, 255 is full power)
            }  
            if (packet.data()+dataStart+1 != 0){  //Repeat for the rest of the bytes of each output
              Output02Time = 10;
              Output02Power = (int)*(packet.data()+dataStart+1);
            }
            if (packet.data()+dataStart+2 != 0){
              Output03Time = 10;
              Output03Power = (int)*(packet.data()+dataStart+2);
            }
            if (packet.data()+dataStart+3 != 0){
              Output04Time = 10;
              Output04Power = (int)*(packet.data()+dataStart+3);
            }
            if (packet.data()+dataStart+4 != 0){
              Output05Time = 10;
              Output05Power = (int)*(packet.data()+dataStart+4);
            }
            if (packet.data()+dataStart+5 != 0){
              Output06Time = 10;
              Output06Power = (int)*(packet.data()+dataStart+5);
            }
            if (packet.data()+dataStart+6 != 0){
              Output07Time = 10;
              Output07Power = (int)*(packet.data()+dataStart+6);
            }
            if (packet.data()+dataStart+7 != 0){
              Output08Time = 10;
              Output08Power = (int)*(packet.data()+dataStart+7);
            }
            if (packet.data()+dataStart+8 != 0){
              Output09Time = 10;
              Output09Power = (int)*(packet.data()+dataStart+8);
            }
            if (packet.data()+dataStart+9 != 0){
              Output10Time = 10;
              Output10Power = (int)*(packet.data()+dataStart+9);
            }
            if (packet.data()+dataStart+10 != 0){
              Output11Time = 10;
              Output11Power = (int)*(packet.data()+dataStart+10);
            }
            if (packet.data()+dataStart+11 != 0){
              Output12Time = 10;
              Output12Power = (int)*(packet.data()+dataStart+11);
            }
            if (packet.data()+dataStart+12 != 0){
              Output13Time = 10;
              Output13Power = (int)*(packet.data()+dataStart+12);
            }
            if (packet.data()+dataStart+13 != 0){
              Output14Time = 10;
              Output14Power = (int)*(packet.data()+dataStart+13);
            }
            if (packet.data()+dataStart+14 != 0){
              Output15Time = 10;
              Output15Power = (int)*(packet.data()+dataStart+14);
            }
            if (packet.data()+dataStart+15 != 0){
              Output16Time = 10;
              Output16Power = (int)*(packet.data()+dataStart+15);
            }       
          }       
      });
      DeviceNameBroadcastCountup = DeviceNameBroadcastCountup + 1;  //Add time to timer for spitting name out for VB.net program to find
      if (DeviceNameBroadcastCountup > 100){ //Send Device name via multicast
        DeviceNameBroadcastCountup = 0; //Reset timer first
        udp.print(deviceName);  //Then spit device name out to network
        udp.broadcast(deviceName);
        digitalWrite(LED_PIN, ledState);  //Flip the LED output
        ledState = (ledState + 1) % 2; // Flip the LED state
      }
  } 
}

void connectToWiFi(){ //This sets up the wifi connection
  int countup = 0;  //A timer to before it gives up, with the code below its like 25 seconds-ish

  if (networkName[0] == '^'){ //First check we have a real name and not the default name for a network SSID
    SerialRecieve();  //If we do, go to USB for a legit one
    return; // once you've left that, gotten one or not, return back to the top, if it is legit, it will skip to the next part, if not, this is repeated
  }

  printLine();  //Make blank line
  Serial.println("Connecting to WiFi network"); //Spit to USB 'connecting'
  Serial.println(networkName);  //Attach the wifi name we're trying to connect to
  WiFi.begin(networkName, networkPswd); //Actual command to the wifi stuff to try and connect
  WiFi.setSleep(false); //Don't let the wifi go to sleep mode

  while (WiFi.status() != WL_CONNECTED){  //If the wifi has not yet connected, remain in this loop
    digitalWrite(LED_PIN, ledState); // Blink LED while we're connecting:
    ledState = (ledState + 1) % 2; // Flip the LED state
    delay(500); //Wait half second
    countup = countup + 1;  //Add time to our timeout
    Serial.print(".");  //Dots dots dots, more dots... ok stops dots
    if (countup == 50){ //If timeout happens
      countup = 0;  //Reset timeout
      Serial.println("Auth Timeout..."); //Tell user the timeout has happened
      memset(networkName, 0, sizeof(networkName));  //Wipe out the wifi credentials to try again
      memset(networkPswd, 0, sizeof(networkPswd)); 
      memset(deviceName, 0, sizeof(deviceName));
      networkName[0] = '^';
      networkPswd[0] = '^';
      deviceNameLen = 0;
      break;  //Exit this 'while' loop cause of timeout
    }
  }
  if (WiFi.status() == WL_CONNECTED){ //However if the wifi was successful
  Serial.println(); //Blank line to USB
  Serial.println("WiFi connected!"); //Tell user it was connected
  Serial.print("IP address: "); //IP is..
  Serial.println(WiFi.localIP()); // Give device's IP
  digitalWrite(LED_PIN, HIGH); //Set LED on
  delay(500); //wait half second
  }
}
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

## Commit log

2020-08-08 Full Version 1
    [Button.stl, Clip.stl, Main Body (1).stl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]
2020-08-09 August 9 2020 Update
    Continuing to update items, BOM, Icon, 3D print 3MFs
    [Button.3mf, Main Body (1).3mf, Main Body Adafruit Battery.3mf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]
2020-08-09 BOM update and 3D update
    Added electronic components to BOM, added hole in the top of the main body so you could see LED.
    [Main Body.stl]
2020-08-11 Cost Breakdown / BOM / New Node
    Cost breakdown added, BOM updated, new 0.75in node added
    [Node2Way-.75in.3mf, NodeBottom2Way-.75in.stl, NodeTop2Way-.75in.stl]
2020-08-12 Aug11-2020 Update
    Fix Controller factory reset
    add binary for controller
    add controller settings screenshots
    Fix live-controller error in VB.NET
    [VRCHaptics.ino]
2020-08-16 Hardware updated
    Added pictures for schematic and board layout for those without Eagle
    [Strip Mount.stl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]
2021-11-27 Individual Node Testing and Improved Connection
    Added individual testing of nodes on the node DataGridView, as well as changing some UDP things on the ESP32 board.
2021-11-28 Self touch update
    Added button to allow you to activate your own nodes to judge where to put them.
2021-12-06 UDP Issue update
    Turns out asking the VB.NET program to join a multicast group was bad? After I removed that the devices stopped disconnecting randomly.
    [VRCHaptics.ino]
2022-07-18 Delay Update
    Tried to add some indication the motor was turning on to the form, only added lag, so i commented that out
2022-07-20 Haptics get stuck on fix
    Turns out having 2 timers was wrong, here's the fix.

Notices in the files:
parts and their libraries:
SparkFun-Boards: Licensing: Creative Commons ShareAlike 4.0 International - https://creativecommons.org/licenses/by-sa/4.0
